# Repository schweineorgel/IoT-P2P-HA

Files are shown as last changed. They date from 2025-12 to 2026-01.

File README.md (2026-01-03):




Demostraciones reales del sistema disponibles en video (ver sección “Demostraciones en video”).

# Sistema IoT descentralizado con ESP32 y ESP-NOW

Sistema de automatización doméstica diseñado para operar de forma autónoma,
segura y tolerante a fallos, utilizando comunicación peer-to-peer entre nodos
ESP32 mediante ESP-NOW, sin dependencia de red Wi-Fi ni broker central.

## Alcance del repositorio y estructura de diseño

Este repositorio documenta el proceso completo de diseño, prototipado, validación experimental e iteración de un sistema IoT descentralizado con ESP32 y ESP-NOW.

Los módulos incluidos pueden encontrarse en distintos estados de abstracción:
- Versiones finales con esquemáticos y diseños PCB.
- Placas de interconexión (solo PCB) orientadas a exponer pines físicos.
- Versiones preliminares o simplificadas utilizadas durante el proceso de
  validación experimental.

Cada módulo se documenta en su propio directorio dentro de `hardware/`,
incluyendo:
- El propósito funcional.
- Nivel de abstracción (esquemático completo, solo PCB, placa de interconexión).
- Relación entre diseño y la implementación física real.
- Decisiones de diseño relevantes y limitaciones conocidas.

La estructura general del directorio `hardware/` es la siguiente:

```
hardware/
├── nodemcu_sensor_pcb
├── nodemcu_ssr_pcb
├── sensor_pcb
└── ssr_pcb
```
Cada uno de estos directorios incluye su propio README detallado.

## Cómo leer este repositorio

Este repositorio no está orientado a la reproducción directa del sistema,
sino a la comprensión del proceso de diseño y validación.

Se recomienda el siguiente orden de lectura:

1. README principal (este archivo), para entender la arquitectura general.
2. Directorio `hardware/`, donde cada módulo cuenta con un README específico.
3. Directorios de firmware y configuración (ESPHome / Home Assistant), según interés.

Cada módulo de hardware debe interpretarse como una unidad independiente,
con su propio contexto, alcance y nivel de madurez.

## Arquitectura general

El sistema está compuesto por nodos ESP32 que toman decisiones localmente y
se comunican entre sí mediante ESP-NOW. La supervisión mediante Home Assistant
es opcional y no afecta la operación del sistema ante caídas de red o servidor.

## Flujo de funcionamiento

1. El nodo sensor detecta presencia mediante radar mmWave.
2. Se evalúa la luminosidad ambiente.
3. Si se cumplen las condiciones, se envía un token de acción vía ESP-NOW.
4. El nodo actuador conmuta la carga y confirma la acción localmente.

## Notas de diseño e iteraciones

Durante el desarrollo del nodo actuador se realizaron varias iteraciones en el
diseño del SSR, motivadas por pruebas prácticas y validación experimental del
comportamiento del circuito.

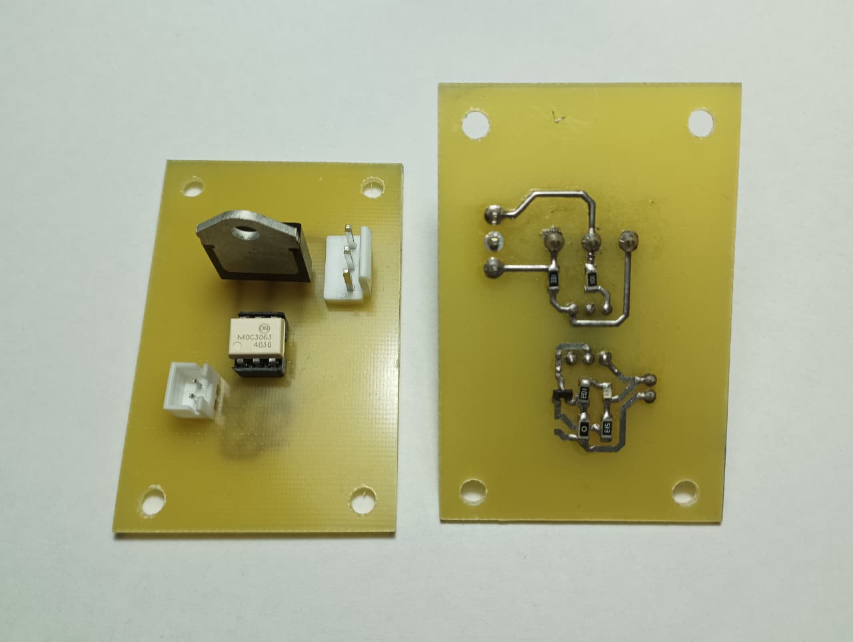
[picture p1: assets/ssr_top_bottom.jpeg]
SSR (Placa del Relé de Estado Sólido)


> En la imagen se observan dos PCBs del SSR diseñado en KiCad: una vista frontal
> y una vista posterior.

En la cara posterior se aprecia la etapa de control basada en un transistor,
cuya resistencia en la base permite regular la amplificación de corriente en el
colector, junto a un LED indicador conectado en paralelo para señalización de
activación.
El emisor del transistor se conecta a tierra mediante un bypass implementado
con una resistencia de 0 Ω.

Esta configuración permite limitar la corriente suministrada al optoacoplador
(MOC), evitando la sobrecarga de los pines GPIO del ESP32 y manteniendo corrientes
de activación seguras, cercanas a los 9 mA por cada SSR activo.

### Desarrollo del SSR

El diseño inicial del SSR se basó en ingeniería inversa de un módulo comercial
capaz de operar con tensiones de control en un rango amplio (aprox. 3 V a 32 V).
Si bien el principio de funcionamiento era correcto, la reproducción directa
del diseño no resultó funcional al implementarse en una PCB propia, presentando
fallas de activación consistentes durante las pruebas.

Ante este comportamiento, se optó por una solución experimental que permitiera
controlar de forma más precisa la corriente de excitación del optoacoplador (MOC).
Para ello, se utilizó el LED indicador, que opera con corrientes del orden de
microamperes, junto con un transistor conectado en paralelo, actuando como una
etapa de control de corriente hacia el MOC, equivalente a una resistencia
variable, aprovechando las características de ganancia (hFE) del transistor.

Esta solución fue implementada y validada en tres SSR independientes, obteniendo
corrientes de activación muy similares entre unidades, lo que permitió confirmar
la reproducibilidad y estabilidad del enfoque.

Una vez validado el comportamiento del SSR en condiciones reales de carga, el
diseño fue posteriormente simplificado en la versión final, eliminando la etapa
activa cuando fue posible y ajustando la limitación de corriente mediante
resistencias, manteniendo un consumo seguro para los GPIO del ESP32.

### Elección del protocolo de comunicación

Inicialmente se evaluó el uso de MQTT como protocolo de comunicación entre nodos.
Sin embargo, debido a la latencia introducida por el broker y a la dependencia
de red, se optó por migrar a ESP-NOW.

El uso de comunicación peer-to-peer permitió reducir la latencia, eliminar
dependencias externas y garantizar la operación local del sistema ante caídas
de red o del servidor de supervisión.

## Fabricación de prototipos

Los prototipos de las placas PCB fueron diseñados en KiCad y posteriormente
fabricados mediante fresado CNC a partir de G-code generado con FlatCAM.

Este enfoque permitió iterar sobre el diseño del SSR, validar
cambios eléctricos en hardware real y ajustar parámetros de corriente y
activación sin depender de servicios externos de fabricación.

## Hardware – Implementación real

### Implementación de los nodos
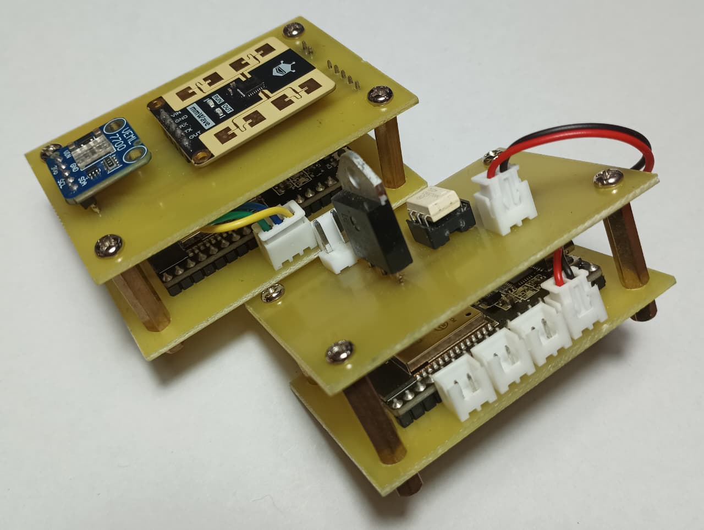
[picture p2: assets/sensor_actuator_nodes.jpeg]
Nodos (Sensores & Actuador)


El sistema está compuesto por dos ESP32 independientes que se comunican entre sí mediante ESP-NOW.
Uno de ellos actúa como nodo sensor, equipado con radar mmWave para detección de presencia y un sensor de luminosidad.
El segundo funciona como nodo actuador e integra un SSR diseñado en KiCad para el control seguro de carga eléctrica.

## Demostraciones en video

A continuación se incluyen videos demostrativos del funcionamiento real del
sistema en condiciones de uso, con el hardware y firmware descritos en este
repositorio.

### Control manual (override)

En este video se muestra el funcionamiento del nodo actuador cuando el sistema
se encuentra en modo *override*, permitiendo la conmutación manual de los SSR
desde Home Assistant.

El control manual no interfiere con la lógica distribuida del sistema y puede
habilitarse o deshabilitarse sin afectar la comunicación ESP-NOW entre nodos.

Control manual del nodo actuador (https://youtu.be/FyrNp5YLqkk)

### Detección de presencia y activación automática

Este video muestra la detección de presencia mediante radar mmWave en el nodo
sensor y la posterior activación automática del nodo actuador bajo condiciones
de baja luminosidad.

La decisión se toma de forma local en el nodo sensor y se comunica al nodo
actuador mediante ESP-NOW, sin dependencia de red Wi-Fi ni servidor central.

Detección de presencia y activación automática (https://youtu.be/x1b7EXLiUZI)

### Home Assistant
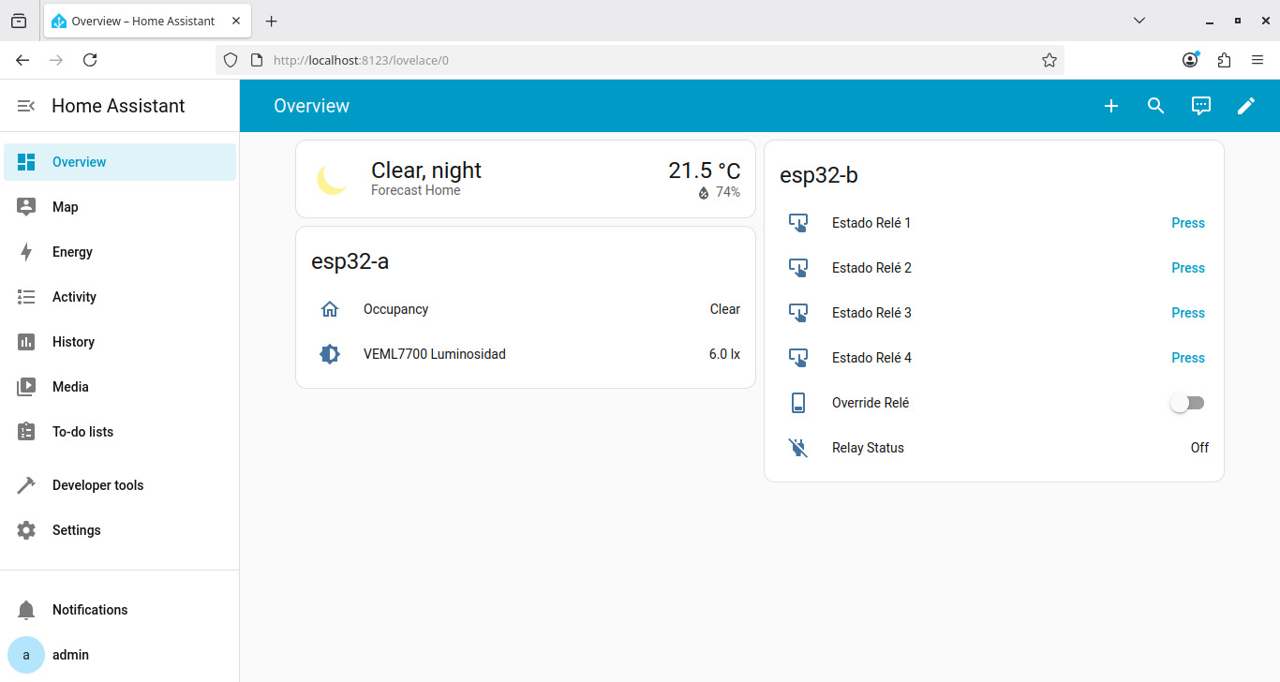
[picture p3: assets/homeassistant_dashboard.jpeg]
Home Assistant dashboard


> Las capturas de pantalla corresponden al servidor de Home Assistant
> ejecutándose en Docker sobre un MacBook Air A1465 utilizado como host de pruebas.

Home Assistant se utiliza como capa de supervisión y control manual (override),
sin actuar como punto único de fallo del sistema.

En el dashboard, el nodo **esp32-a** corresponde al nodo sensor, donde se
visualiza el estado de presencia detectada y el nivel de luminosidad ambiental
medido en lux.

El nodo **esp32-b** corresponde al nodo actuador. Desde este se permite el
control manual de hasta cuatro SSR independientes cuando el modo *override*
está habilitado. En modo automático, los SSR se activan de forma simultánea
cuando el nodo sensor (**esp32-a**) envía un token de activación al detectar
presencia bajo condiciones de baja luminosidad.

Los SSR permanecen activos mientras se mantenga la detección de presencia en
la habitación, desactivándose automáticamente al cesar dicha condición.

### ESPHome
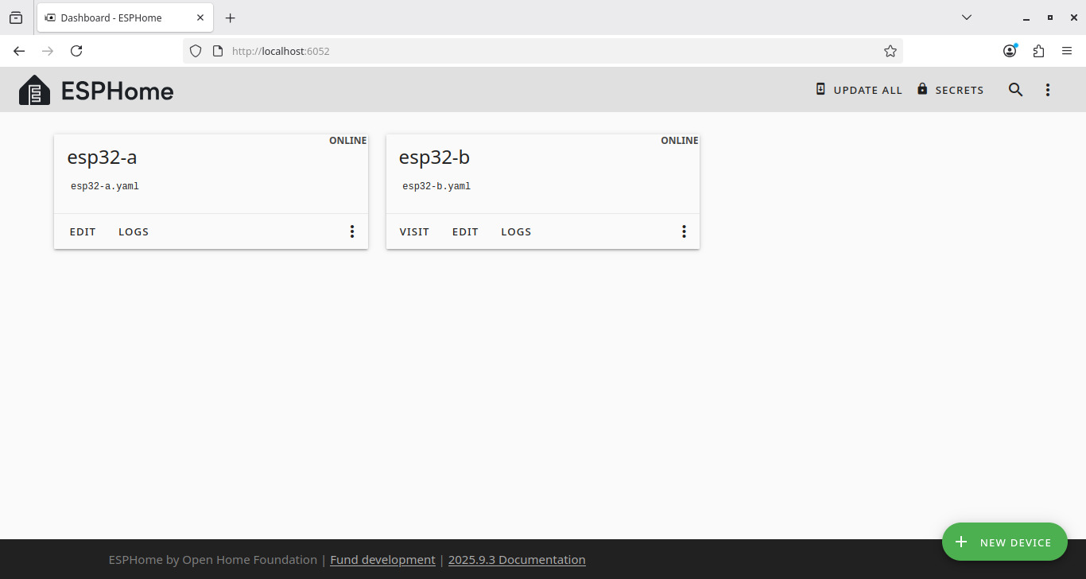
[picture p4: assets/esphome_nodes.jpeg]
ESPHome nodes


ESPHome se emplea para la configuración y el monitoreo de los nodos ESP32.

## Estado del proyecto

El sistema se encuentra en un estado funcional y estable a nivel experimental.
No se contemplan nuevas funcionalidades mayores en el corto plazo, aunque
podrían realizarse mejoras menores o ajustes documentales.

El repositorio tiene como objetivo principal servir como referencia técnica
del proceso de diseño, prototipado e iteración de un sistema IoT descentralizado.

## Colaboración

El diseño del hardware, el desarrollo del firmware y la documentación del
sistema fueron realizados por el autor de este repositorio.

El ensamblaje y la soldadura de los prototipos fueron realizados con el apoyo
de un colaborador durante la etapa de prototipado.

## Tecnologías aplicadas
ESP32 | ESPHome | ESP-NOW | Home Assistant | Docker | Debian 12 | KiCad | YAML

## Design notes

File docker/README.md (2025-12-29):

# IoT Descentralizado - Docker Setup
Este repositorio contiene la configuración de contenedores Docker para la integración de Home Assistant y ESPHome en un sistema IoT autónomo basado en ESP32 y ESP-NOW.

## Contenedores incluidos
- **Home Assistant**: Orquestado en Debian 12 mediante Docker, para monitoreo y override manual.
- **ESPHome**: Orquestado en Debian 12 mediante Docker, para flasheo y gestión de ESP32.

## Requisitos
- Debian 12 o equivalente
- Docker y Docker Compose instalados
- Red local (solo para Home Assistant; los ESP32 funcionan peer-to-peer vía ESP-NOW)

## Instalación

1. Clonar el repositorio:
```bash
git clone <repo_url>
cd <repo_folder>
```

2. Iniciar contenedores:

`docker-compose up -d`

Acceder a Home Assistant en:
http://host:8123

Acceder a ESPHome en:
http://host:6052 (si se expone el dashboard web)

## Estructura
```
docker/
├── docker-compose.yml
└── README.md
```

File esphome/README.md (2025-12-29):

# IoT Descentralizado - ESPHome
Firmware para ESP32 en un sistema de automatización doméstica descentralizada usando ESP-NOW, diseñado para funcionar incluso sin conexión a la red Wi-Fi o servidor central.

## Dispositivos
- ESP32 Sensor
Sensores: radar mmWave (presencia) y sensor de luminosidad (lux)
Función: detecta presencia y luminosidad, y envía un token de acción al actuador mediante ESP-NOW si se cumplen ciertas condiciones.

- ESP32 Actuador
Control: carga eléctrica mediante SSR diseñado en KiCad
Función: recibe token del sensor y activa/desactiva la carga; mantiene sincronización local aunque Home Assistant esté desconectado.

## Comunicación
- Peer-to-peer vía ESP-NOW, independiente de Wi-Fi o servidor central.

>Inicialmente se probó MQTT, pero se descartó por su alta latencia y vulnerabilidad de seguridad.

## Instalación y flasheo

1. Conectar el ESP32 al computador.

2. Flashear usando dashboard de ESPHome.
- `actuator_node.yaml` 
- `sensor_node.yaml`

Verificar logs para confirmar conexión y estado.
(No olvidar ingresar las direcciones MAC de los ESP32 en el secrets.yaml)

## Estructura de archivos
```
esphome/
├── sensor_node.yaml
├── actuator_node.yaml
├── secrets.yaml.example
└── README.md
```

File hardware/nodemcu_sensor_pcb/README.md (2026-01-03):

## Diseño PCB

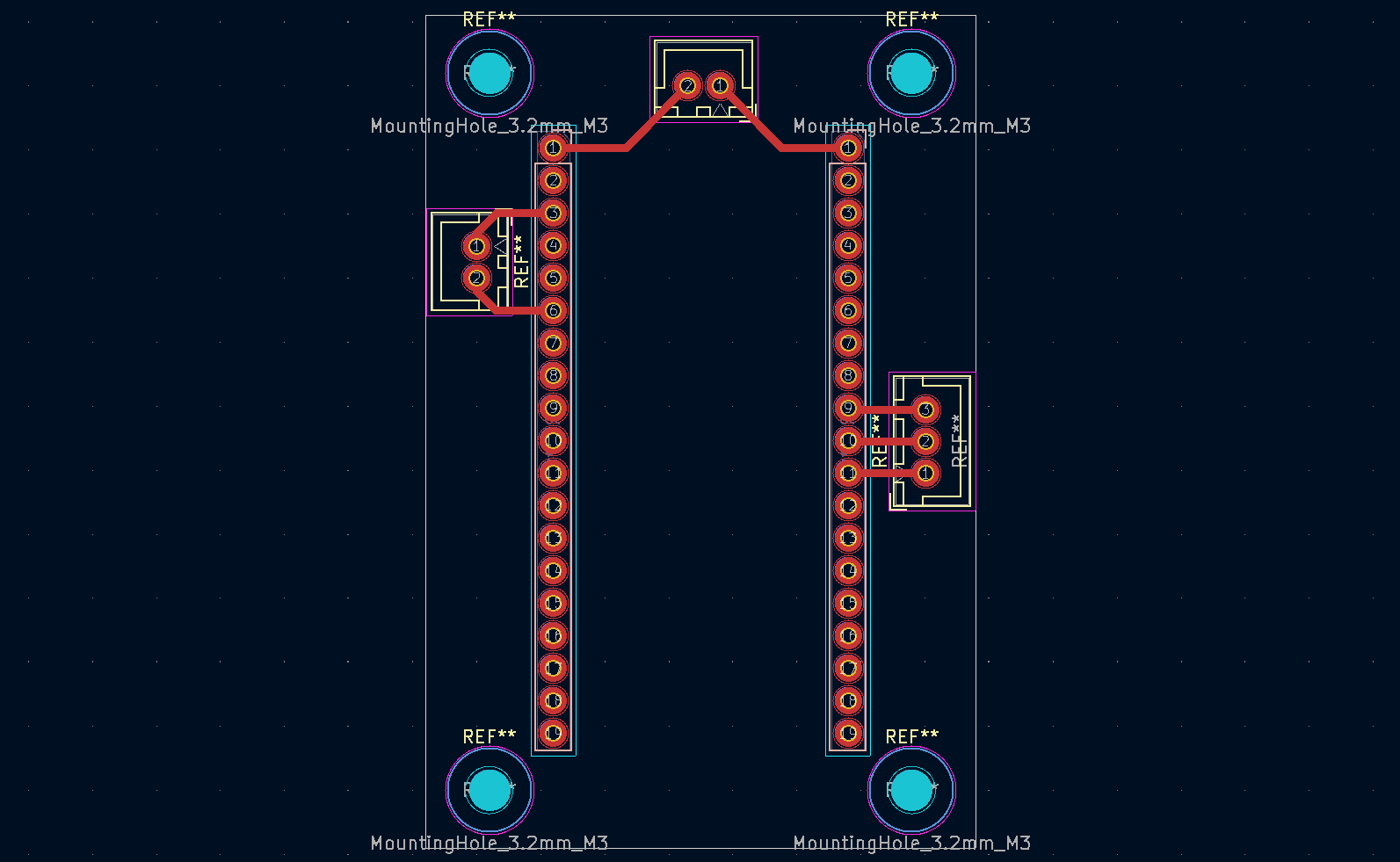
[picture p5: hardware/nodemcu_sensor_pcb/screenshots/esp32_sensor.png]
PCB - Vista PCB


Este diseño corresponde al NodeMCU del nodo sensor y, al igual que el PCB del
nodo actuador, fue desarrollado únicamente a nivel de layout PCB, sin un
esquemático formal asociado.

El diseño se realizó considerando las dimensiones físicas y disposición de
pines del NodeMCU (ESP32), actuando como una placa de interconexión entre el
microcontrolador y la placa de sensores externa.

Se expusieron los siguientes pines del ESP32 para la integración de sensores:

- **SDA / SCL**: bus I²C utilizado para la comunicación con el sensor de
  luminosidad VEML7700.
- **GPIO25 (TX) / GPIO26 (RX)**: interfaz UART empleada para la configuración y
  comunicación con el radar mmWave C4001, permitiendo su operación en modo
  detección de presencia.
- **GPIO27**: entrada digital conectada al pin OUT del sensor mmWave,
  utilizada para indicar detección de presencia.
- **3.3 V y GND**: alimentación de la placa de sensores directamente desde el
  ESP32.

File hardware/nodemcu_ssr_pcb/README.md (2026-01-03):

## Diseño PCB

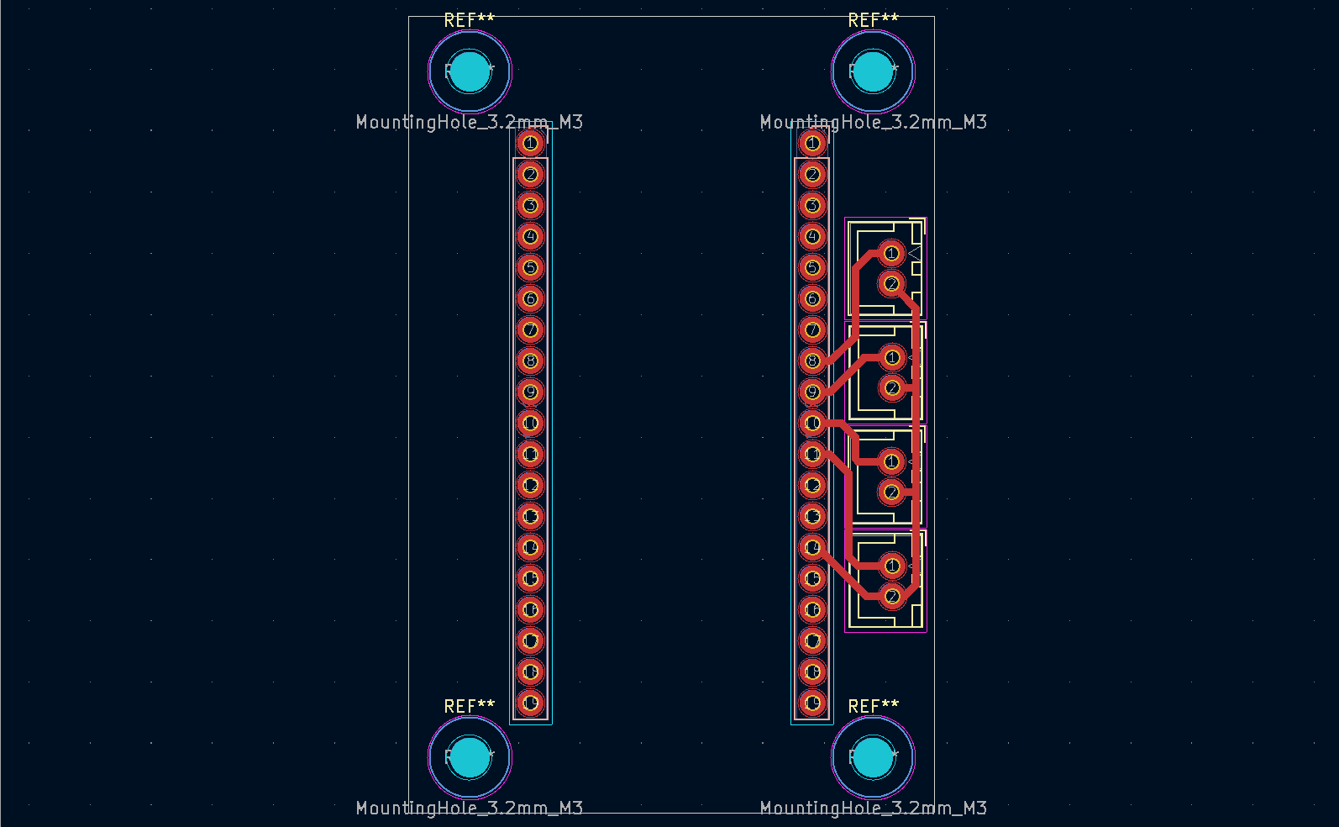
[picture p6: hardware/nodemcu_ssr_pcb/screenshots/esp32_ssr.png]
PCB - Vista PCB


Este diseño corresponde al nodo actuador y fue desarrollado únicamente a
nivel de layout PCB, sin una representación formal de esquemático.

La placa fue diseñada tomando como referencia las dimensiones físicas y
disposición de pines del NodeMCU (ESP32), actuando como una base de
interconexión para el control de hasta cuatro SSR externos previamente
diseñados.

En el PCB se exponen directamente los siguientes pines del ESP32:
- **GPIO33**
- **GPIO25**
- **GPIO26**
- **GPIO27**

Cada uno de estos GPIO está destinado al control de un SSR independiente,
permitiendo accionar hasta cuatro cargas de manera simultánea o individual,
según la lógica implementada en el firmware.

El nodo actuador no requiere conexión física con el nodo de sensores, ya
que la comunicación entre ambos se realiza de forma inalámbrica mediante
ESP-NOW, manteniendo el desacoplamiento funcional y físico entre sensado
y actuación.

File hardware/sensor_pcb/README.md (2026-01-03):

## Diseño PCB

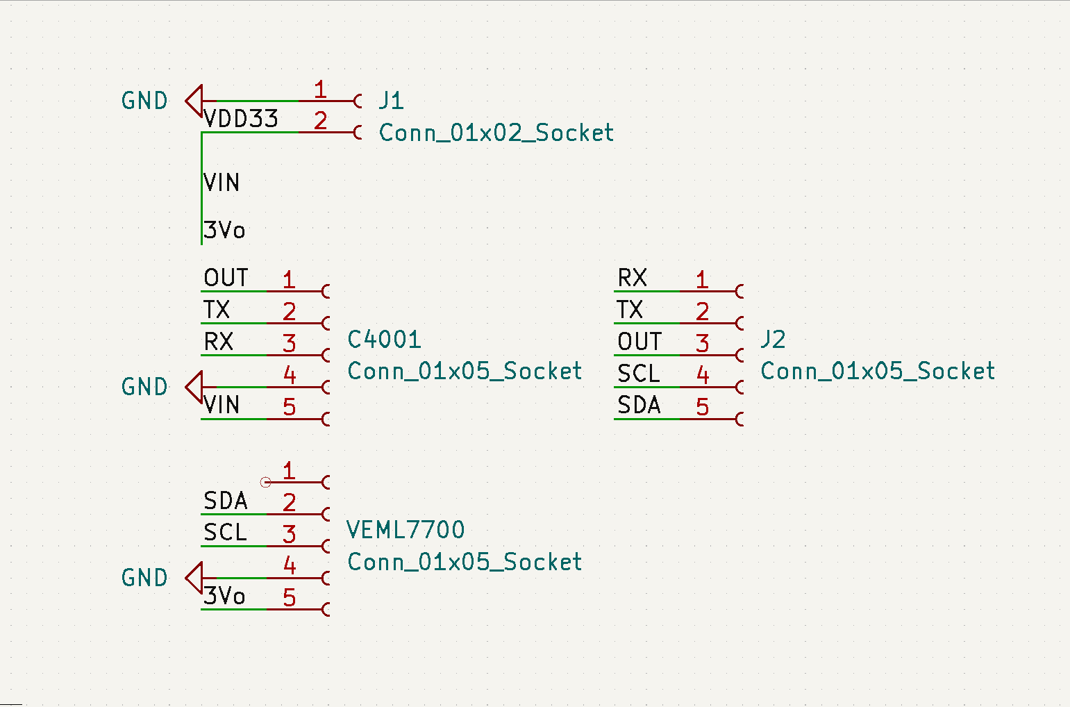
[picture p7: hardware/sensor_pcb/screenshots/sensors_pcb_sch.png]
PCB - Vista superior

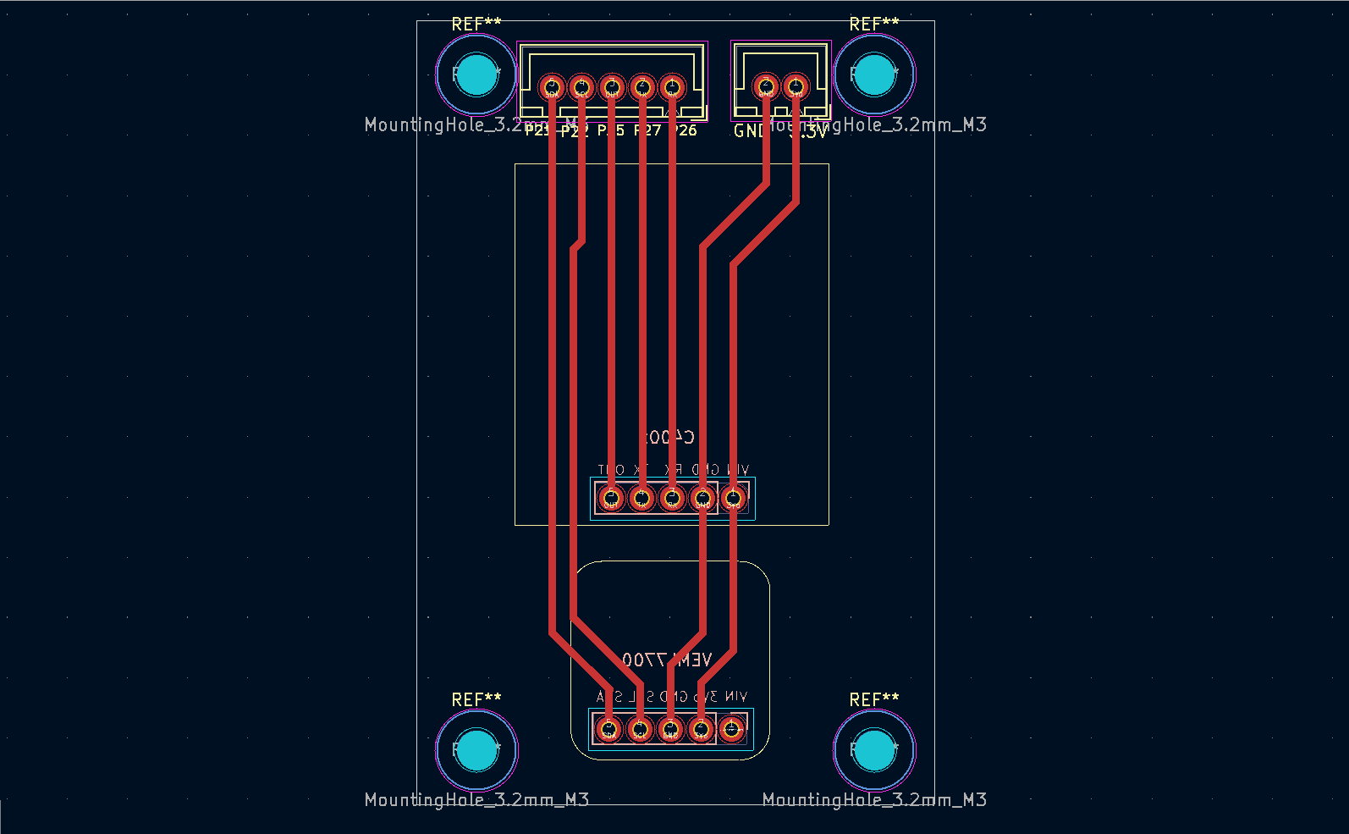
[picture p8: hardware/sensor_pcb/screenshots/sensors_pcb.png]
PCB - Vista inferior


Esta placa corresponde a una placa de sensores dedicada, no a un nodo
independiente. Su función es alojar, alimentar y exponer las señales de los
sensores hacia una placa principal basada en ESP32 (NodeMCU).

El diseño integra un radar de presencia mmWave C4001 y un sensor de luminosidad
VEML7700, sin lógica de procesamiento propia. Ambos dispositivos son
alimentados directamente desde el pin de 3,3 V del ESP32, al cual esta
placa se conecta mediante un conector dedicado.

La placa actúa como interfaz eléctrica y mecánica entre los sensores y el
ESP32, dejando disponibles las siguientes señales:
- RX / TX para la comunicación con el radar mmWave.
- I²C (SDA / SCL) para el sensor de luminosidad.
- Alimentación y referencia a tierra comunes.

Este enfoque modular permite:
- Separar físicamente los sensores del microcontrolador.
- Facilitar pruebas, reemplazo de sensores y futuras iteraciones.
- Mantener el PCB del ESP32 libre de componentes específicos de sensado.

El PCB fue diseñado en KiCad y pensado para prototipado rápido mediante
fresado CNC.

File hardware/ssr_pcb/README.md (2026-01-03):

## Diseño PCB

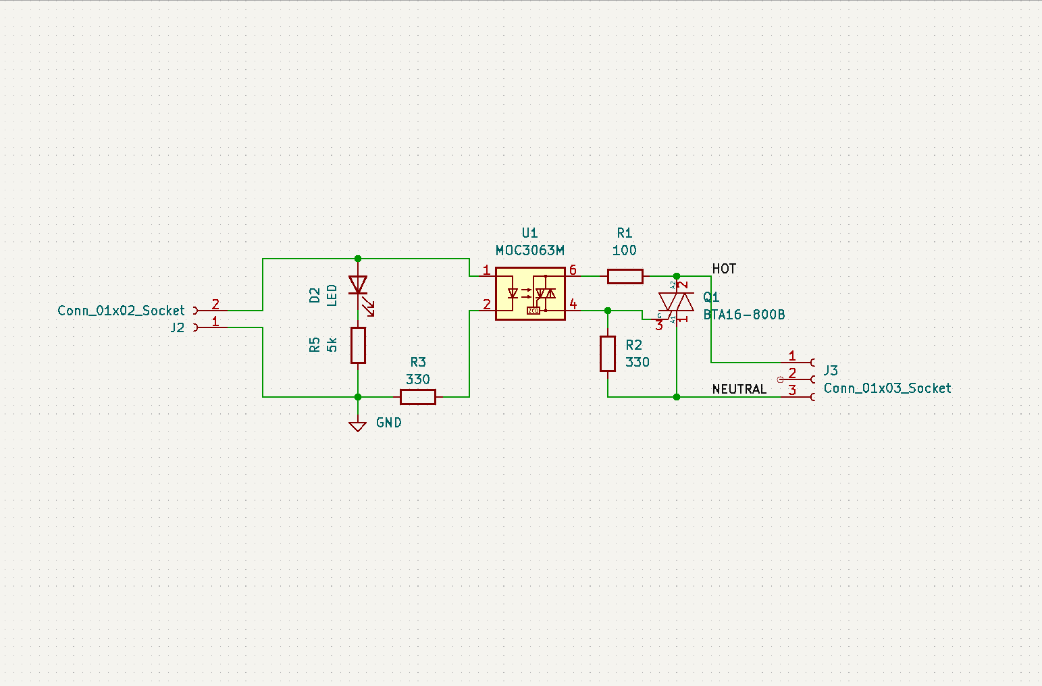
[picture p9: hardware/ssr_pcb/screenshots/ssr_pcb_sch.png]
PCB - Vista superior

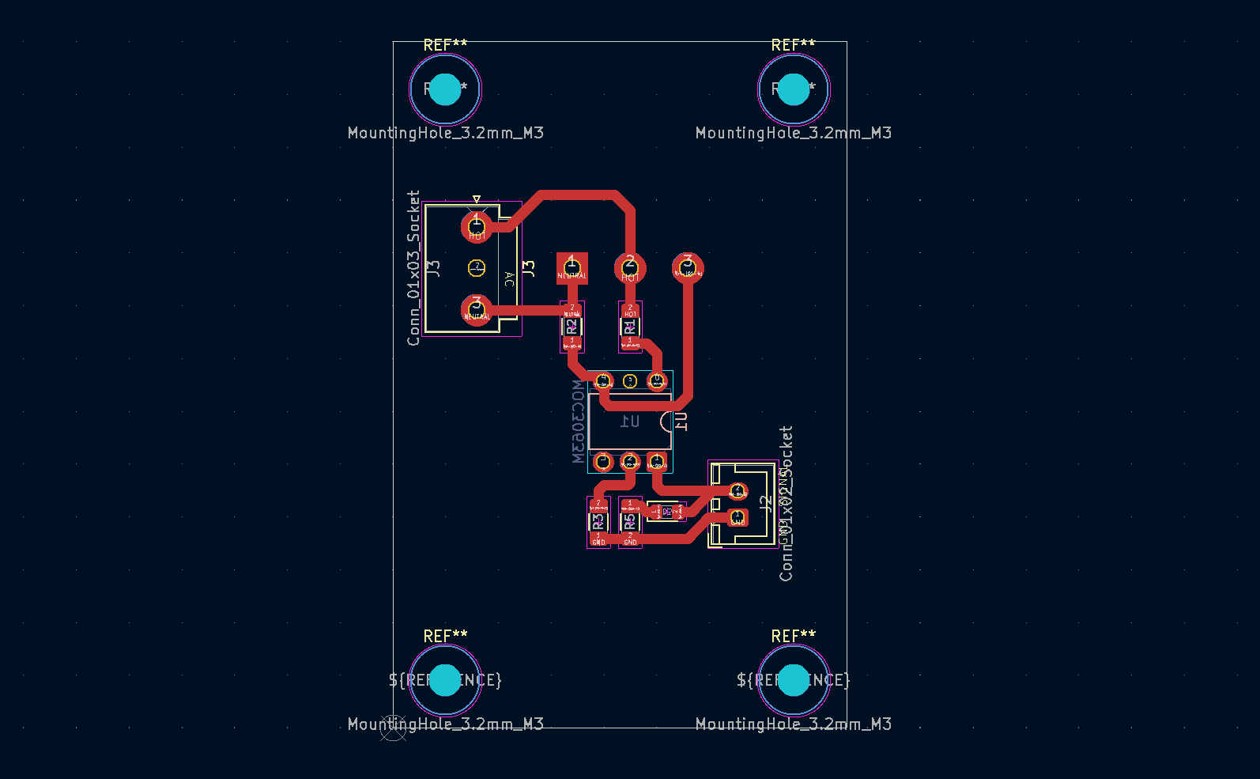
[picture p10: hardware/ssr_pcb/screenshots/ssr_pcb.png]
PCB - Vista inferior


> **Nota sobre el esquemático final**  
> El esquemático y la vista PCB del SSR incluidos en este repositorio
> corresponden a una versión posterior del diseño y no coinciden
> exactamente con la implementación física utilizada en los prototipos
> funcionales.
>
> La PCB mostrada en el README principal corresponde a una versión
> preliminar validada experimentalmente, que incorpora una etapa de
> control basada en un transistor para limitar la corriente de excitación
> del optoacoplador (MOC).
>
> La versión documentada en este directorio refleja una iteración
> simplificada del diseño, donde la limitación de corriente se realiza
> exclusivamente mediante una resistencia en serie, manteniendo un LED
> indicador conectado en paralelo.

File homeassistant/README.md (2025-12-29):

## Rol de Home Assistant

Home Assistant se utiliza exclusivamente como capa de supervisión y control manual.

- No se ejecuta ninguna lógica de automatización crítica en Home Assistant.
- El sistema continúa funcionando de forma autónoma.
- ESPHome y ESP-NOW gestionan todas las decisiones en tiempo real.

Este diseño garantiza resiliencia ante fallos de red o servidor.

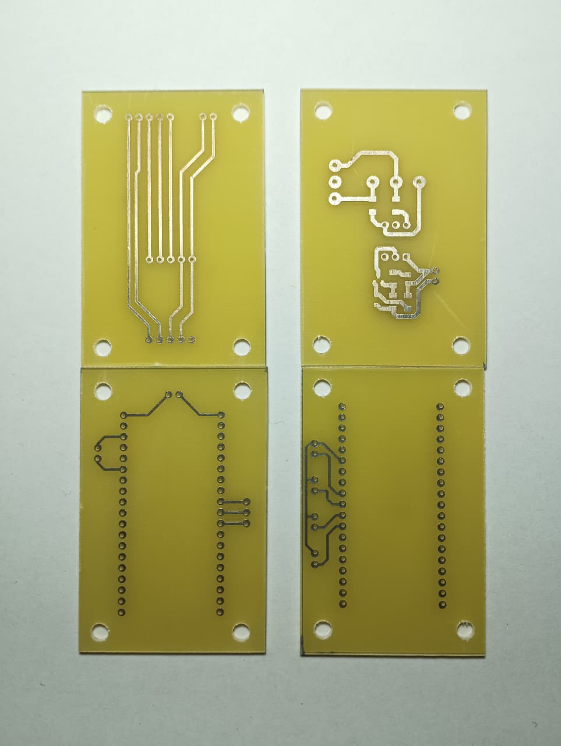
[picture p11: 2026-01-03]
assets/PCBs.jpeg

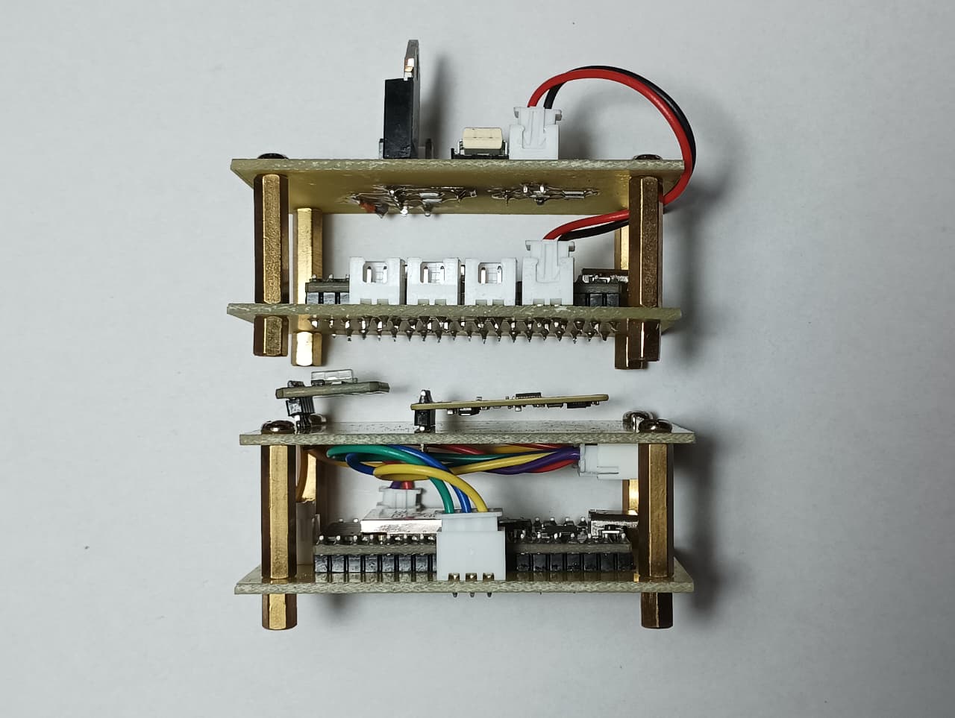
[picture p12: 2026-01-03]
assets/nodes_side.jpeg

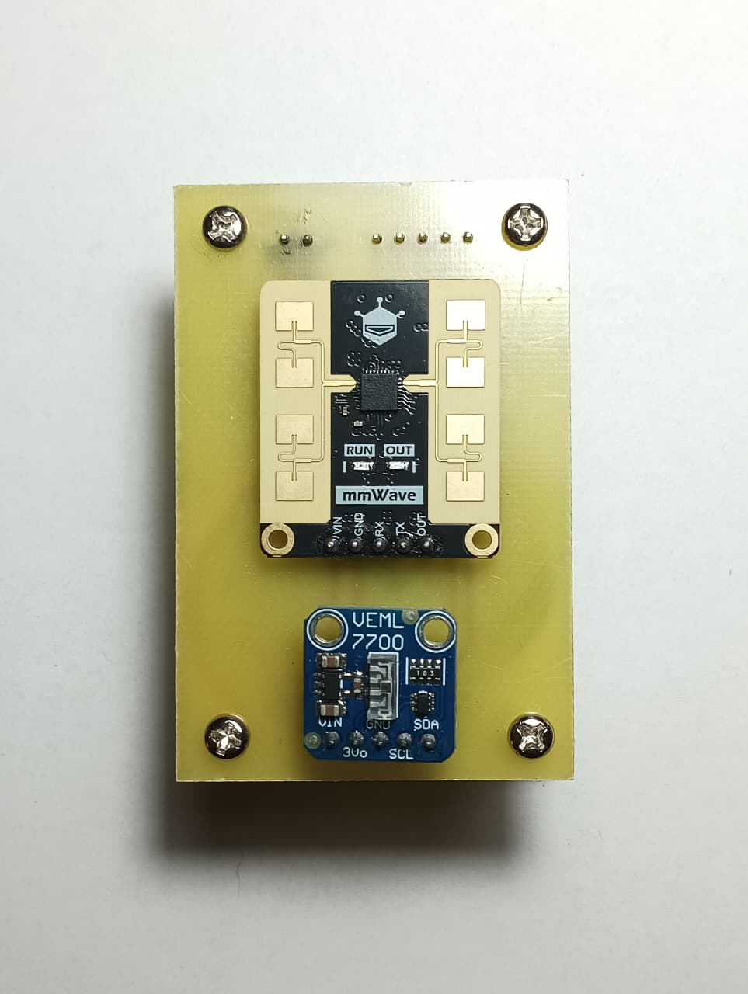
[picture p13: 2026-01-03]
assets/sensor_top.jpeg

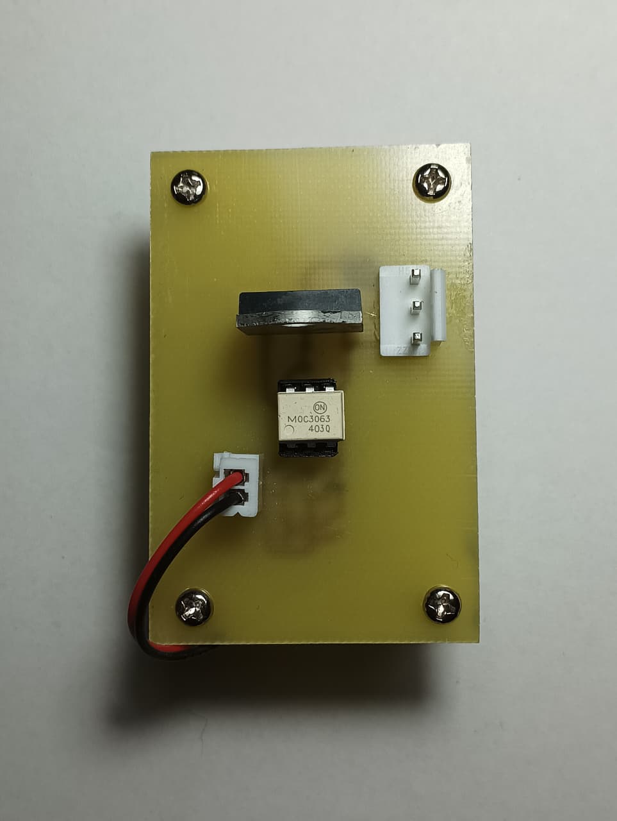
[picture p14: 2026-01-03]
assets/actuator_top.jpeg

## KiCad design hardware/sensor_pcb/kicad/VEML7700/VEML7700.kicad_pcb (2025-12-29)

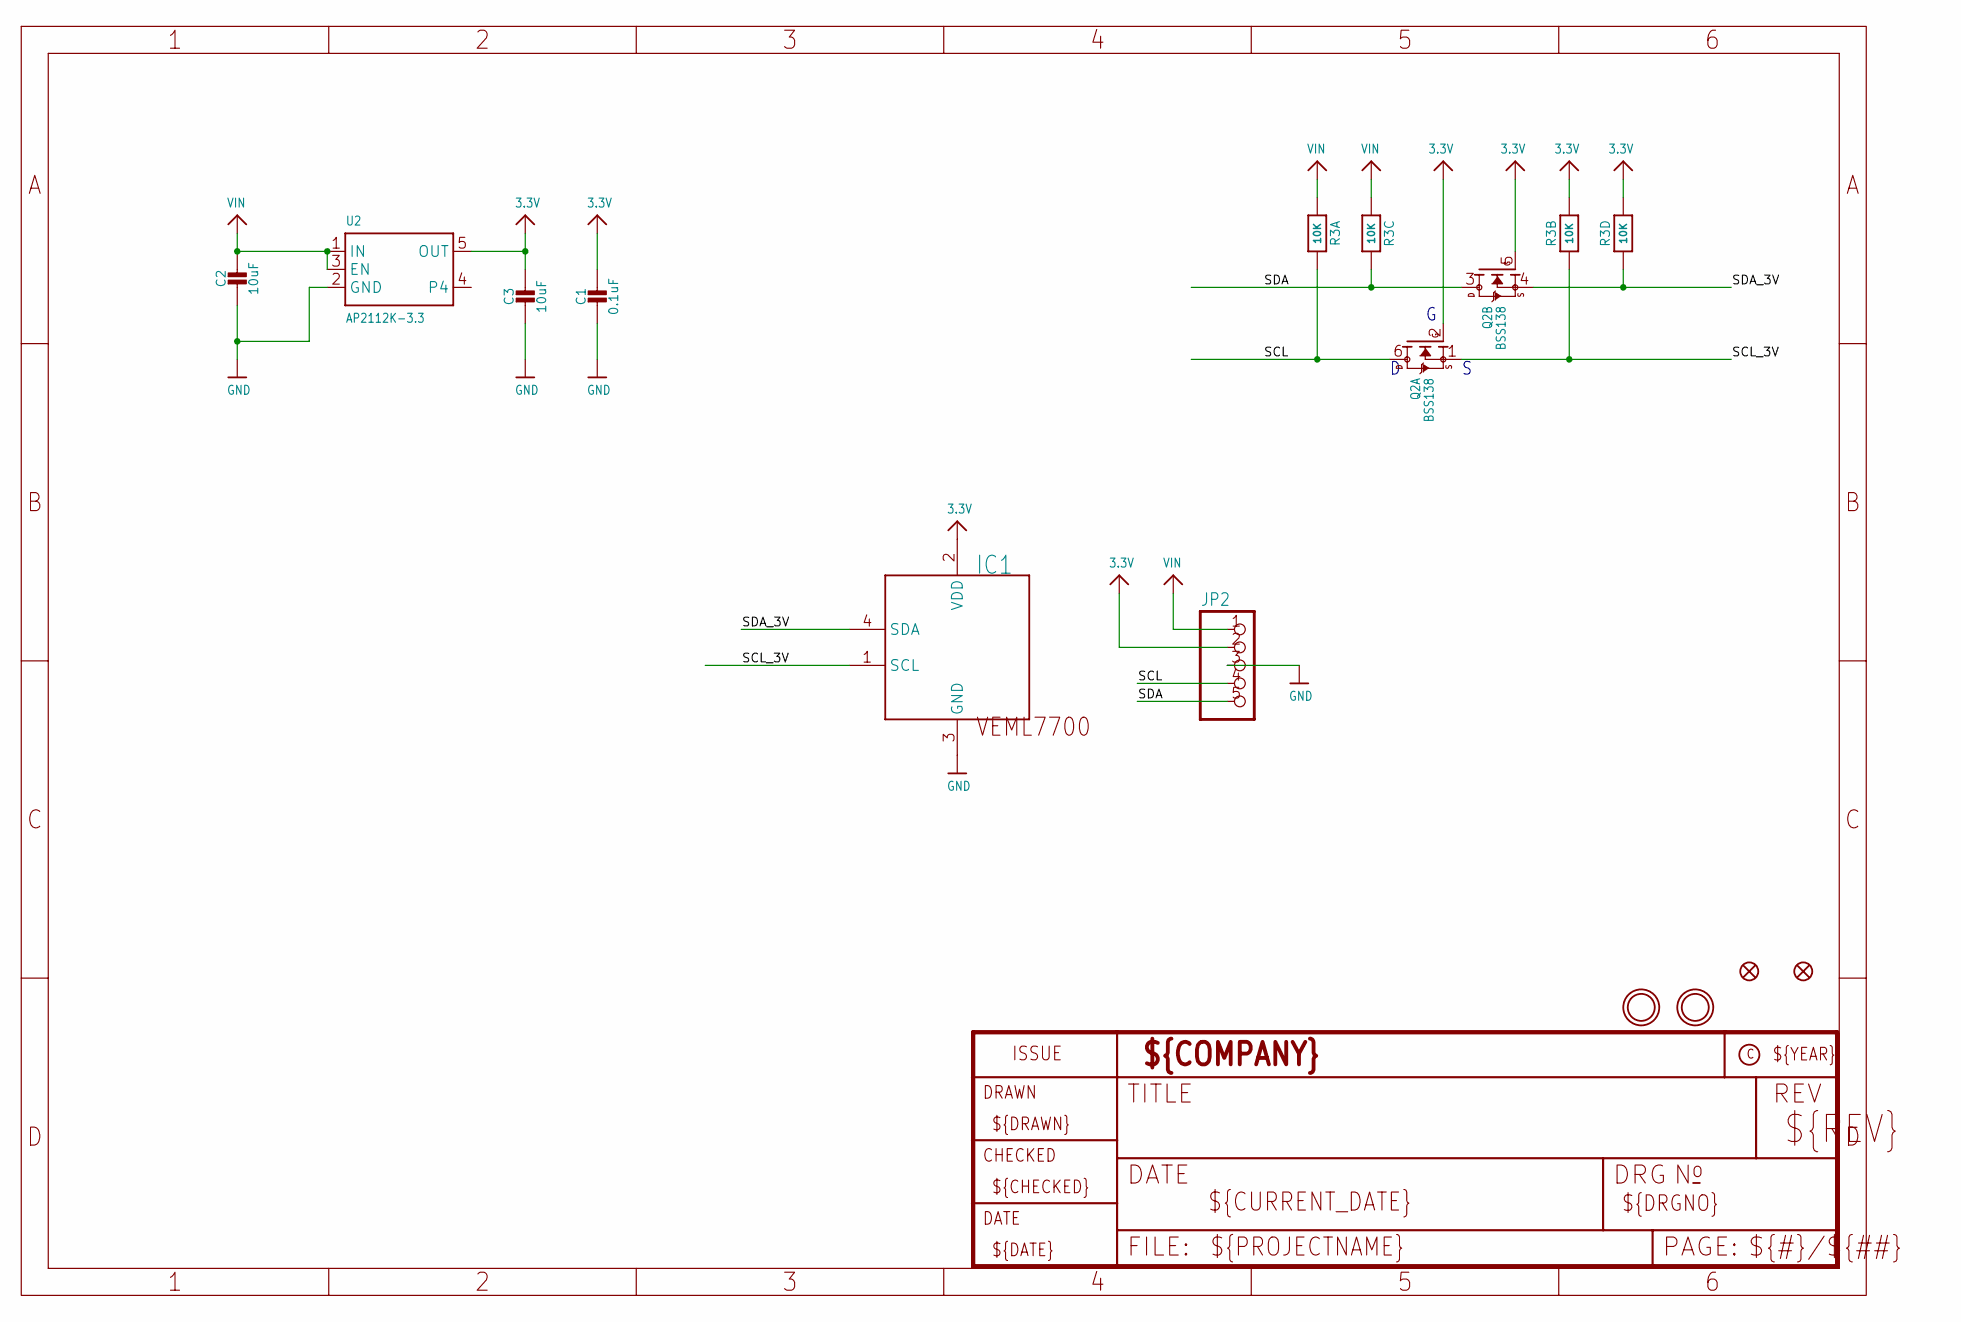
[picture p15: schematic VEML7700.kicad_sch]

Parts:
C1: 0.1uF; 0603-NO
C2, C3: 10uF; 0805-NO
FID1, FID2: FIDUCIAL_1MM
IC1: VEML7700
JP2: HEADER-1X5ROUND; 1X05_ROUND
Q2: BSS138; SOT363
R3: 10K; RESPACK_4X0603
U2: AP2112K-3.3; SOT23-5
U$3, U$4: MOUNTINGHOLE2.5; MOUNTINGHOLE_2.5_PLATED

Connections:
3.3V: C1.1, C3.1, IC1.2 (VDD), JP2.2, Q2.2 (G), Q2.5 (G), R3.2 (1), R3.4 (1), U2.5 (OUT)
GND: C1.2, C2.2, C3.2, IC1.3 (GND), JP2.3, U2.2 (GND)
SCL: JP2.4, Q2.6 (D), R3.8 (2)
SCL_3V: IC1.1 (SCL), Q2.1 (S), R3.7 (2)
SDA: JP2.5, Q2.3 (D), R3.6 (2)
SDA_3V: IC1.4 (SDA), Q2.4 (S), R3.5 (2)
VIN: C2.1, JP2.1, R3.1, R3.3 (1), U2.1 (IN), U2.3 (EN)

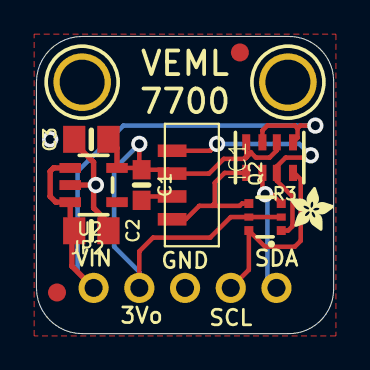
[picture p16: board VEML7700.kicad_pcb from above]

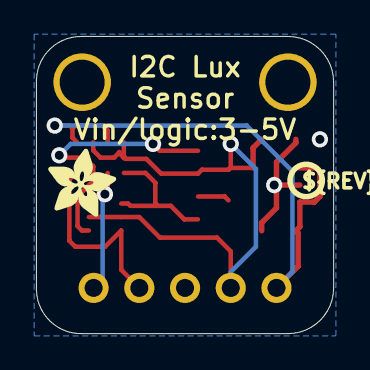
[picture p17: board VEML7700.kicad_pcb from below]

Board: 2 copper layers, 16.5 x 16.5 mm, 16 parts (3 on the bottom side), 7 nets.

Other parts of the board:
U$1: ADAFRUIT_3.5MM
U$8: ADAFRUIT_2.5MM
U$12: KATTNI_STOP
U$27: PCBFEAT-REV-040

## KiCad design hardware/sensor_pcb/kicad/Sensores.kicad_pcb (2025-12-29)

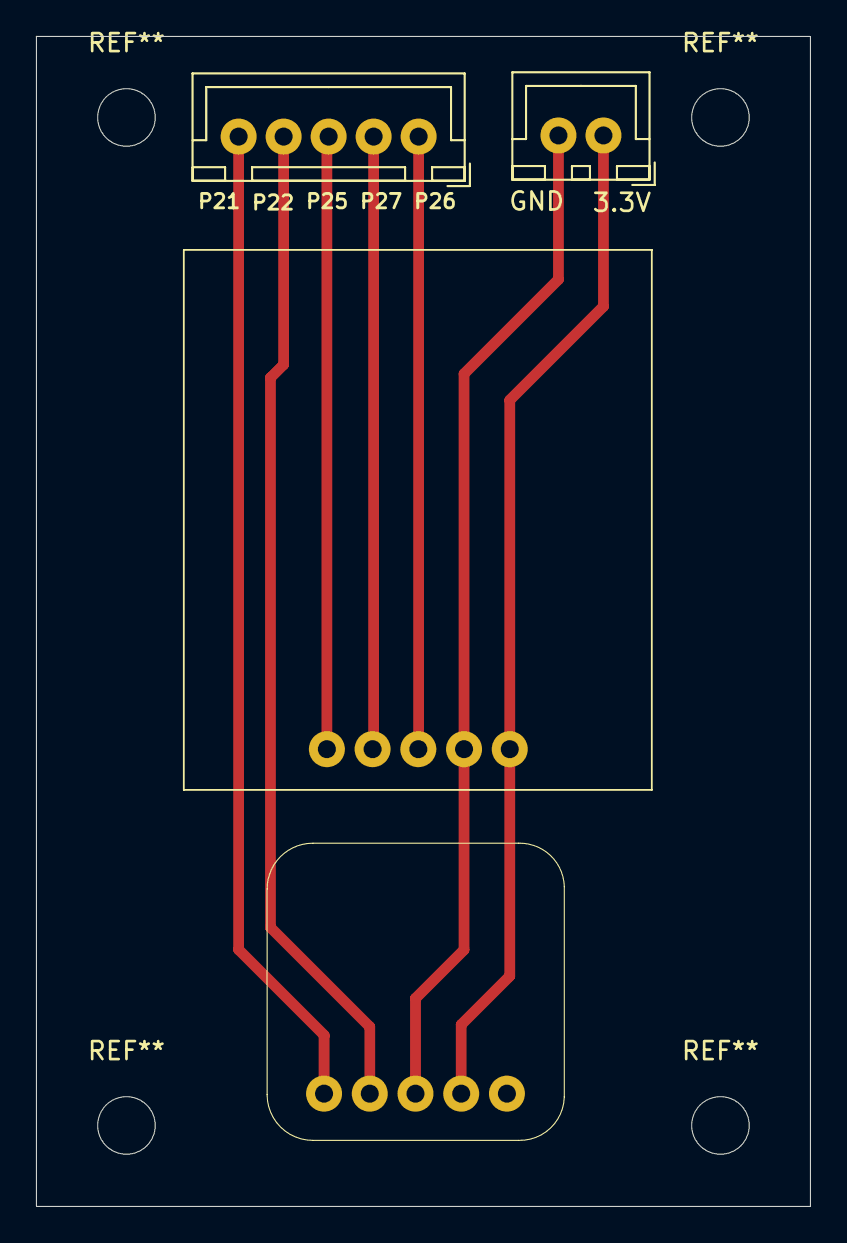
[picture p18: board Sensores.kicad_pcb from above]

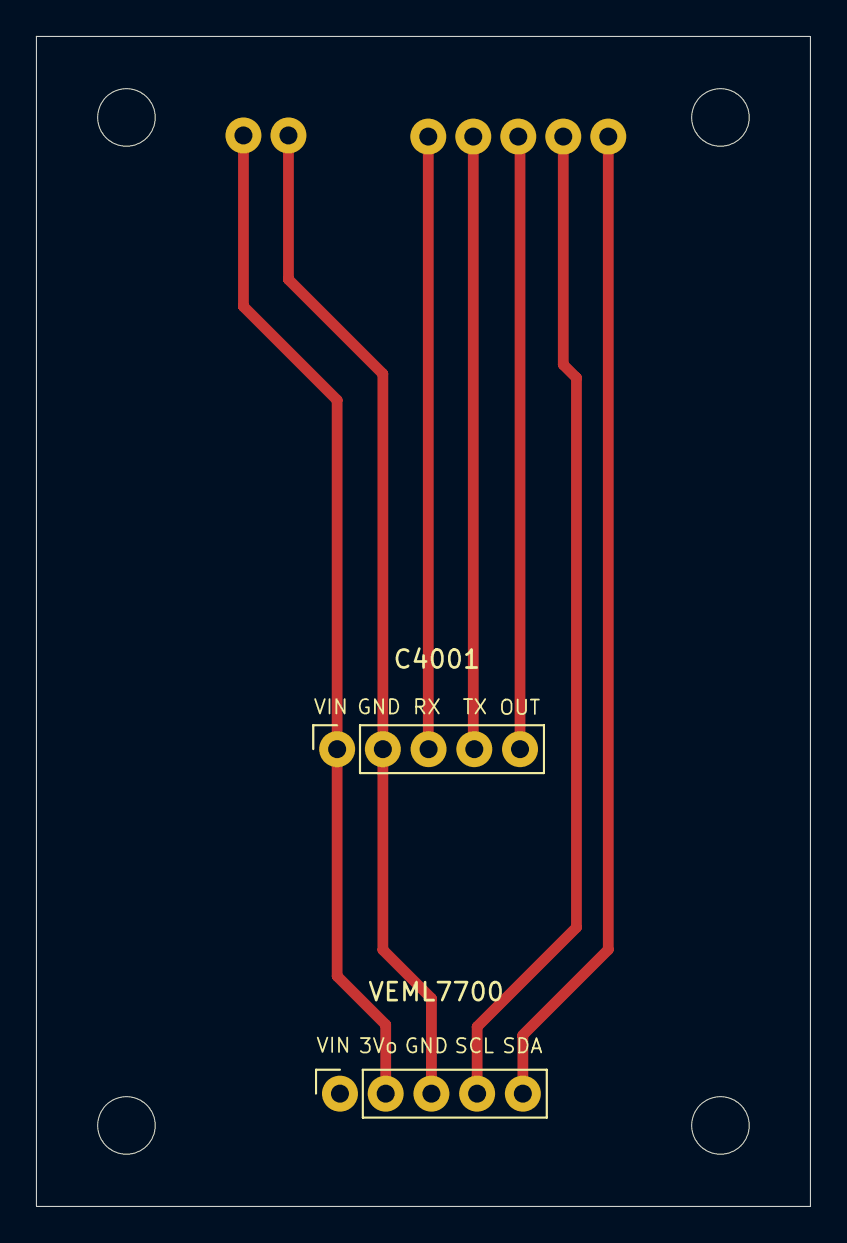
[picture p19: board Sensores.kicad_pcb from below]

Board: 2 copper layers, 43.0 x 65.0 mm, 4 parts (2 on the bottom side), 7 nets.

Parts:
3.3V: Conn_01x02_Socket; JST_XH_B2B-XH-A_1x02_P2.50mm_Vertical
C4001: Conn_01x05_Socket; PinSocket_1x05_P2.54mm_Vertical
J2: Conn_01x05_Socket; JST_XH_B5B-XH-A_1x05_P2.50mm_Vertical
VEML7700: Conn_01x05_Socket; PinSocket_1x05_P2.54mm_Vertical

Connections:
/3Vo: 3.3V.1, C4001.1, VEML7700.2
/OUT: C4001.5, J2.3
/RX: C4001.3, J2.1
/SCL: J2.4, VEML7700.4
/SDA: J2.5, VEML7700.5
/TX: C4001.4, J2.2
GND: 3.3V.2, C4001.2, VEML7700.3

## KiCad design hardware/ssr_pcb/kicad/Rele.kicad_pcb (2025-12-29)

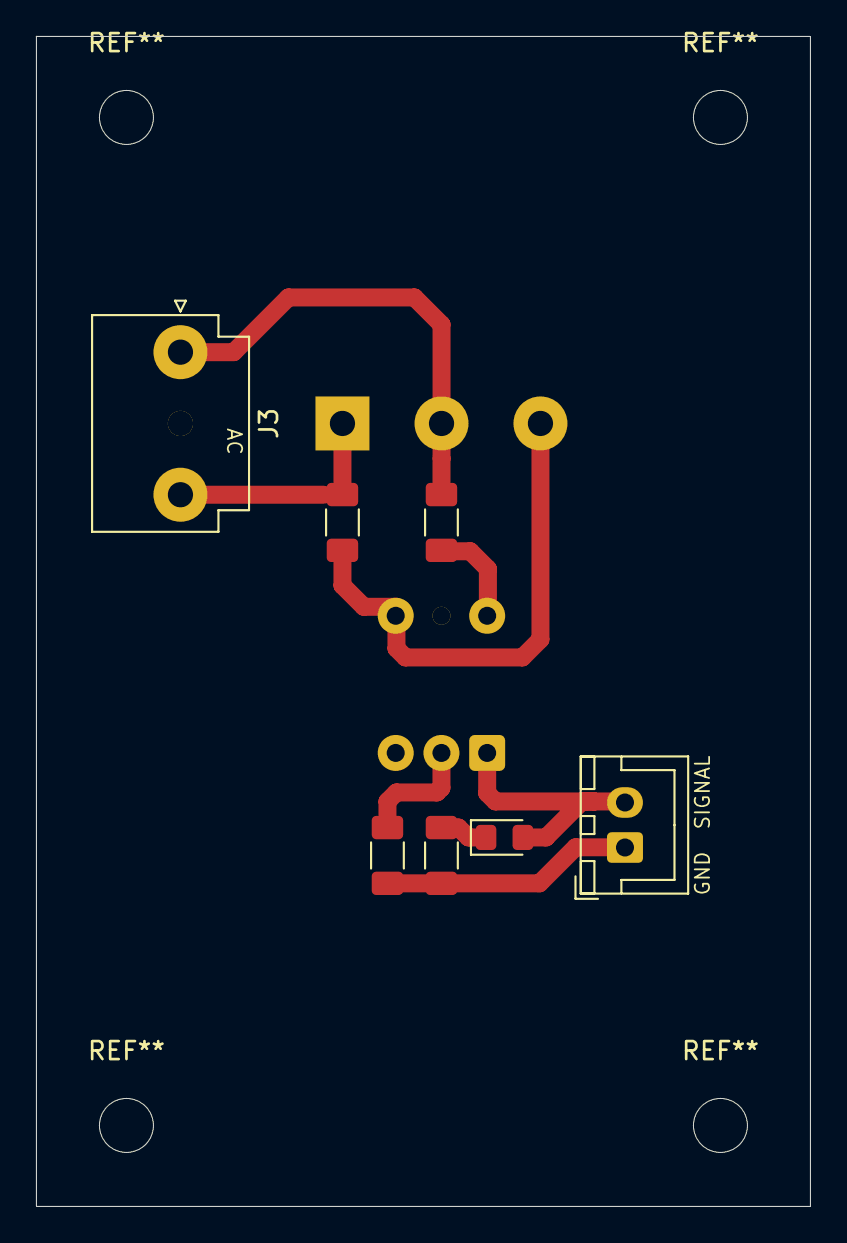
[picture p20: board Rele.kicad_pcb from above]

Board: 2 copper layers, 43.0 x 65.0 mm, 8 parts (1 on the bottom side), 8 nets.

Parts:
D2: LED; LED_0805_2012Metric_Pad1.15x1.40mm_HandSolder
J2: Conn_01x02_Socket; JST_XH_B2B-XH-A_1x02_P2.50mm_Vertical
J3: Conn_01x03_Socket; JST_VH_B3P-VH_1x03_P3.96mm_Vertical
R1: 100; R_1206_3216Metric_Pad1.30x1.75mm_HandSolder
R2, R3: 330; R_1206_3216Metric_Pad1.30x1.75mm_HandSolder
R5: 10k; R_1206_3216Metric_Pad1.30x1.75mm_HandSolder
U1: MOC3063M; DIP-6_W7.62mm

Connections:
/HOT: J3.1, R1.2
/NEUTRAL: J3.3, R2.2
GND: J2.1, R3.1, R5.2
unnamed: D2.2 (A), J2.2, U1.1
unnamed: D2.1 (K), R5.1
unnamed: R2.1, U1.4
unnamed: R1.1, U1.6
unnamed: R3.2, U1.2

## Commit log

2026-01-03 added reference images for the sensor and actuator nodes. Updated README
2026-01-03 update schematic view for ssr and add screenshots with a README explaining design
    [Rele.kicad_sch]
2026-01-03 added pcb and schematic screenshots to add to README for the design
2026-01-03 added README and screenshots for the actuator node's PCB
2026-01-03 Added README and screenshots for sensor node's PCB design

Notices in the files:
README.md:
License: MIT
